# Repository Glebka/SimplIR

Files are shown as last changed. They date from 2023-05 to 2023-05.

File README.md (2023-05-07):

# SimplIR

The project of a joined IR Remote for controlling both Samsung LE26B450 TV and unknown TV Box that uses RC5 IR protocol.
SimplIR allows to switch TV On and Off, control volume and switch channels on TV Box.

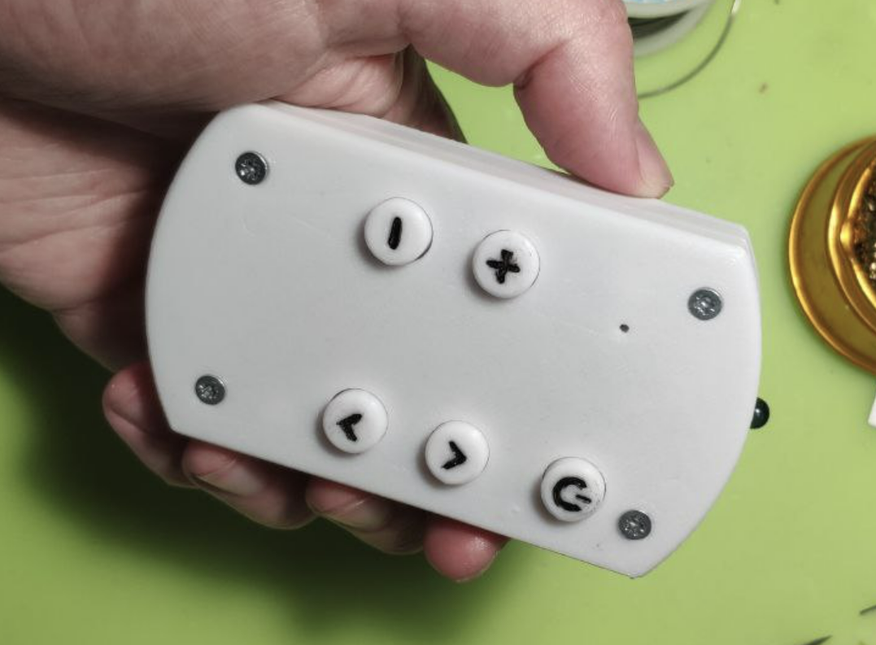
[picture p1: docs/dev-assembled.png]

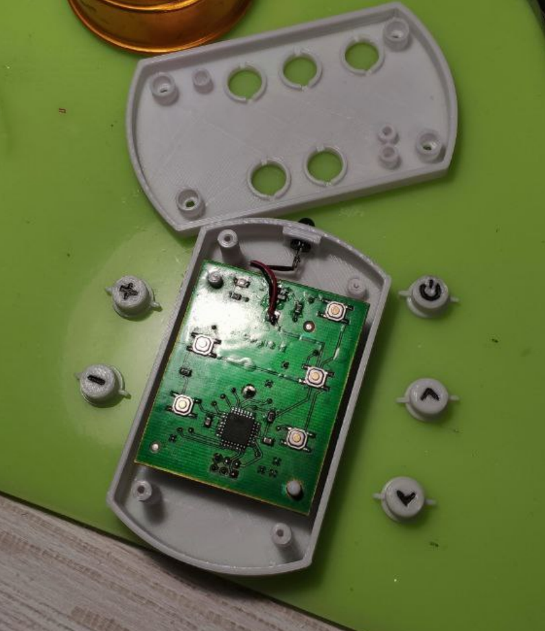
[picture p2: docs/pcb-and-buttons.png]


## Hardware and Software

* ATmega48PA MCU with Arduino based firmware
* 5 tactile buttons
* 1 5mm IR LED
* CR-2030 battery
* Firmware uses [Arduino-IRremote](https://github.com/Arduino-IRremote/Arduino-IRremote) for sending codes to the TV Set and TV Box
* Low power consumption - 0.1 uA, when in sleep mode (most of the time)

## TODO

* increase IR LED power, probably, add more LEDs in parallel
* add external crystal to guarantee precise timings
* deal with low recognition rate of ON/OFF signal for Samsung TV

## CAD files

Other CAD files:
cad/simplir-enclosure.FCStd

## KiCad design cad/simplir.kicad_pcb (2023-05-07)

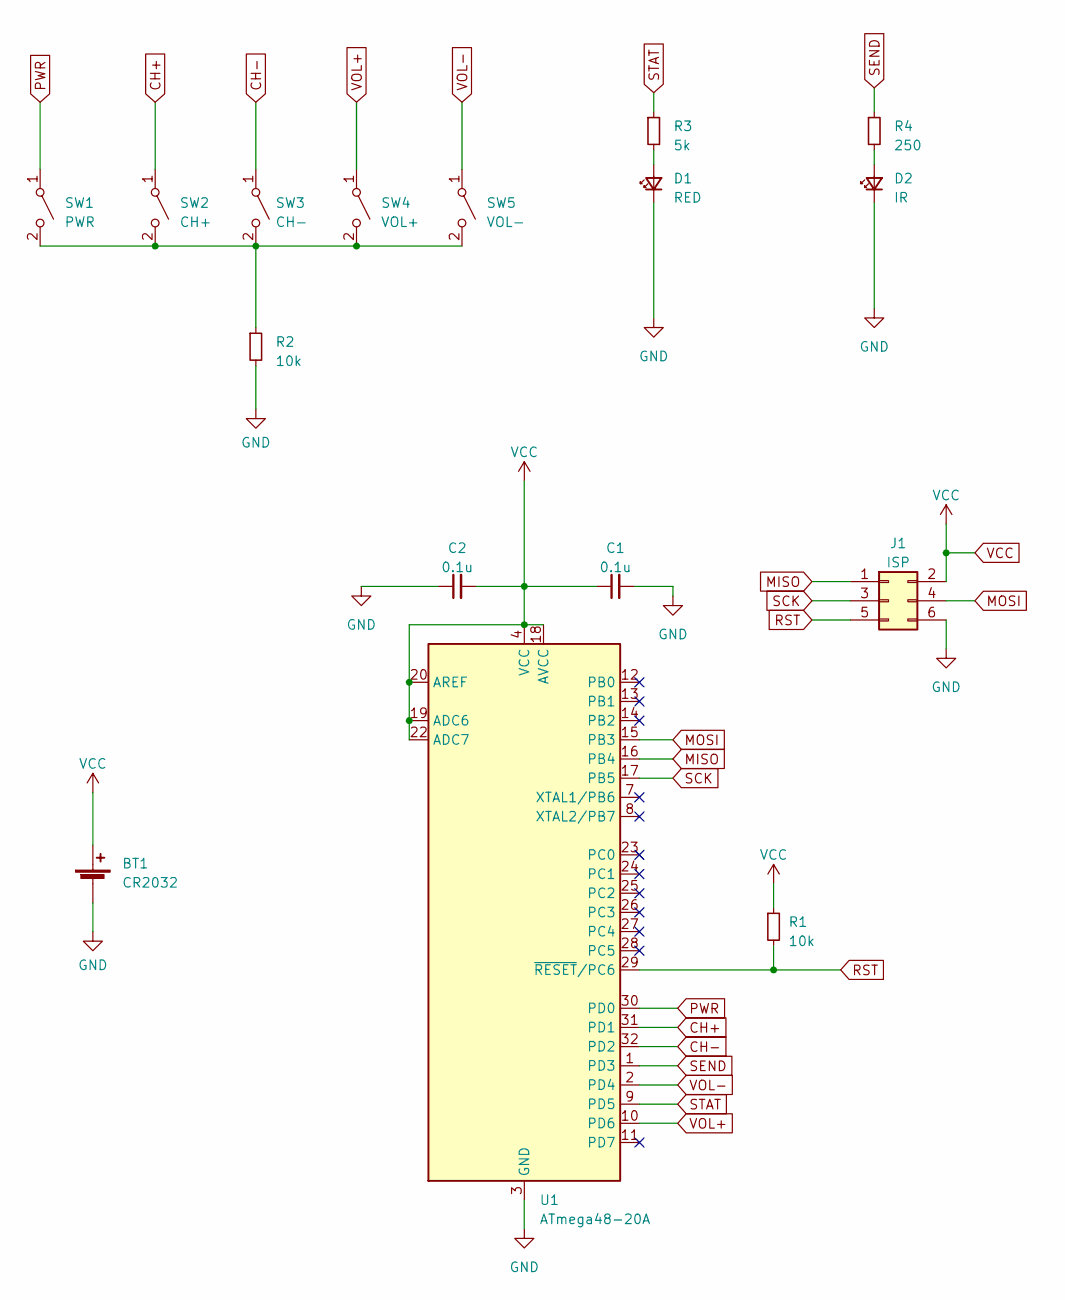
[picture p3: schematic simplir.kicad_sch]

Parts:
BT1: CR2032; BatteryHolder_Keystone_106_1x20mm
C1, C2: 0.1u; C_0805_2012Metric
D1: RED; LED_1206_3216Metric
D2: IR; LED_D5.0mm_IRGrey
J1: ISP; PinHeader_2x03_P2.54mm_Vertical
R1, R2: 10k; R_0805_2012Metric
R3: 5k; R_0805_2012Metric
R4: 250; R_0805_2012Metric
SW1: PWR; SW_SPST_TL3342
SW2: CH+; SW_SPST_TL3342
SW3: CH-; SW_SPST_TL3342
SW4: VOL+; SW_SPST_TL3342
SW5: VOL-; SW_SPST_TL3342
U1: ATmega48-20A; TQFP-32_7x7mm_P0.8mm

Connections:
CH+: SW2.1 (A), U1.31 (PD1)
CH-: SW3.1 (A), U1.32 (PD2)
GND: BT1.2 (-), C1.2, C2.1, D1.1 (K), D2.1 (K), J1.6, R2.2, U1.3 (GND), U1.5 (GND), U1.21 (GND)
MISO: J1.1, U1.16 (PB4)
MOSI: J1.4, U1.15 (PB3)
unnamed: D1.2 (A), R3.2
unnamed: D2.2 (A), R4.2
unnamed: R2.1, SW1.2 (B), SW2.2 (B), SW3.2 (B), SW4.2 (B), SW5.2 (B)
PWR: SW1.1 (A), U1.30 (PD0)
RST: J1.5, R1.2, U1.29 (~RESET/PC6)
SCK: J1.3, U1.17 (PB5)
SEND: R4.1, U1.1 (PD3)
STAT: R3.1, U1.9 (PD5)
VCC: BT1.1 (+), C1.1, C2.2, J1.2, R1.1, U1.4 (VCC), U1.6 (VCC), U1.18 (AVCC), U1.19 (ADC6), U1.20 (AREF), U1.22 (ADC7)
VOL+: SW4.1 (A), U1.10 (PD6)
VOL-: SW5.1 (A), U1.2 (PD4)

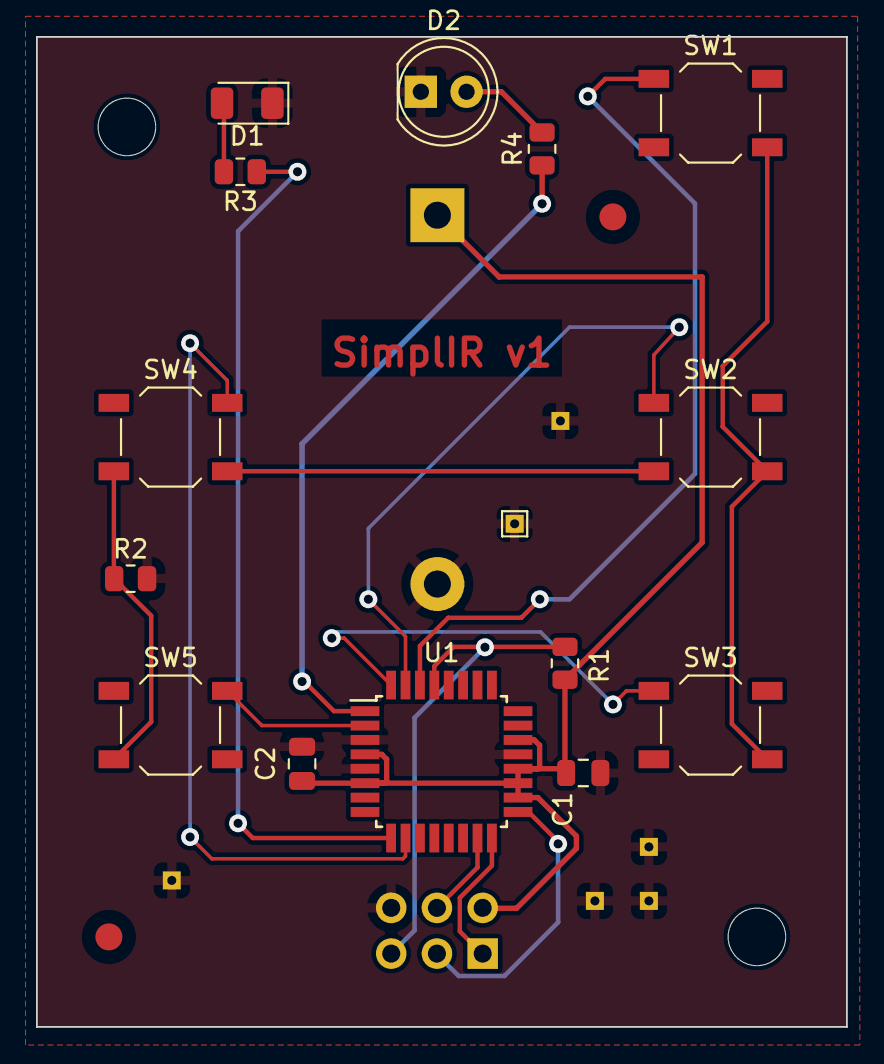
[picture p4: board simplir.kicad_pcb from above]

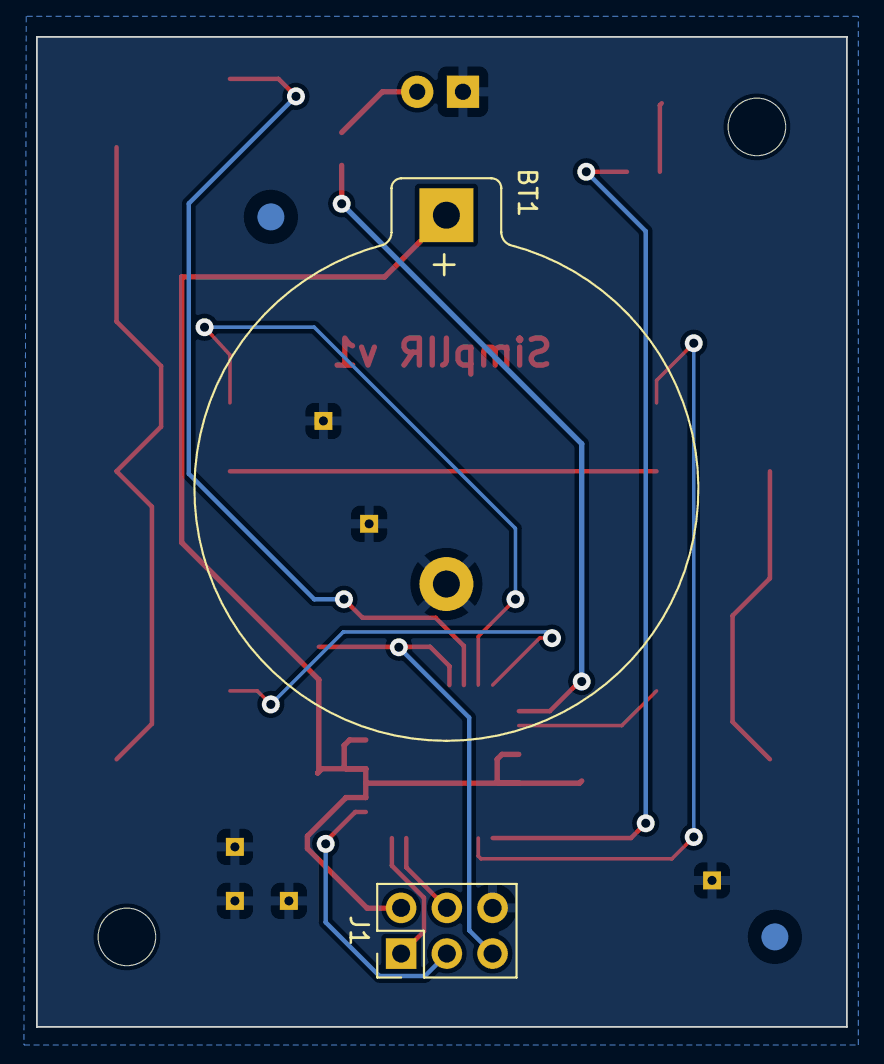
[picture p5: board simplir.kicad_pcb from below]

Board: 2 copper layers, 45.0 x 55.0 mm, 16 parts (2 on the bottom side), 16 nets.

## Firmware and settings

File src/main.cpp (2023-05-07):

#include <Arduino.h>
#define DISABLE_CODE_FOR_RECEIVER
#define SEND_PWM_BY_TIMER
#define IR_USE_AVR_TIMER2
#include <IRremote.hpp>
#include <TimerOne.h>
#include <avr/power.h>
#include <avr/sleep.h>

#define IR_LED_PIN (PD3)
#define LED_FEEDBACK_PIN (PD5)
#define TICK_INTERVAL (30000)
#define IDLE_TICKS_TIMEOUT (5)

/*
PWR   - PD0
CH+   - PD1
CH-   - PD2
VOL-  - PD4
VOL+  - PD6
*/

namespace Buttons
{
  enum
  {
    BTN_PWR,
    CH_PLUS,
    CH_MINUS,
    VOL_MINUS,
    VOL_PLUS,
    COUNT_
  };
}

typedef void (*SendFunc)(uint16_t, uint16_t);

struct ButtonHandler
{
  SendFunc send;
  uint16_t addr;
  uint16_t cmd;
};

void send_rc5(uint16_t addr, uint16_t cmd)
{
  IrSender.sendRC5((uint8_t)addr, (uint8_t)cmd, 0);
}

void send_samsung(uint16_t addr, uint16_t cmd)
{
  IrSender.sendSamsung(addr, cmd, 0);
}

volatile uint8_t button_pins[Buttons::COUNT_] = {PD0, PD1, PD2, PD4, PD6};
volatile uint8_t buttons_prev_state[Buttons::COUNT_] = {1, 1, 1, 1, 1};
volatile uint8_t buttons_state[Buttons::COUNT_] = {1, 1, 1, 1, 1};
volatile uint8_t tick = 0;
volatile uint8_t ticks_since_last_event = 0;
ButtonHandler button_handlers[Buttons::COUNT_] = {
    {send_samsung, 0x707, 0x2},
    {send_rc5, 0xE, 0x3C},
    {send_rc5, 0xE, 0x11},
    {send_rc5, 0xE, 0x13},
    {send_rc5, 0xE, 0x12},
};

void inc_tick()
{
  tick++;
  ticks_since_last_event++;
}

void setup()
{
  // disable ADC
  ADCSRA = 0;

  // turn off various modules
  power_all_disable();

  // but enable the necessary ones
  power_timer0_enable();
  power_timer1_enable();
  power_timer2_enable();

  // set input with pull-up for all ports
  DDRB = 0;
  DDRC = 0;
  DDRD = 0;
  PORTB = 255;
  PORTC = 255;
  PORTD = 255;

  // IR Led pin should be OUTPUT
  pinMode(IR_LED_PIN, OUTPUT);
  digitalWrite(IR_LED_PIN, LOW);

  // Feedback pin is OUTPUT as well
  pinMode(LED_FEEDBACK_PIN, OUTPUT);
  digitalWrite(LED_FEEDBACK_PIN, LOW);

  // enable interrupts for PD
  PCICR |= 0b00000100;

  // enable interrupts for D0, D1, D2, D4, D6
  PCMSK2 |= 0b01010111;

  IrSender.begin(true, LED_FEEDBACK_PIN);
  Timer1.initialize(TICK_INTERVAL);
  Timer1.attachInterrupt(inc_tick);
}

void power_down()
{
  set_sleep_mode(SLEEP_MODE_PWR_DOWN);
  cli();
  sleep_enable();
  sleep_bod_disable();
  sei();
  sleep_cpu();
}

void idle()
{
  set_sleep_mode(SLEEP_MODE_IDLE);
  cli();
  sleep_enable();
  sleep_bod_disable();
  sei();
  sleep_cpu();
}

void read_pins()
{
  for (uint8_t i = 0; i < Buttons::COUNT_; i++)
  {
    buttons_state[i] = digitalRead(button_pins[i]);
  }
}

void update_previous_state()
{
  for (uint8_t i = 0; i < Buttons::COUNT_; i++)
  {
    buttons_prev_state[i] = buttons_state[i];
  }
}

uint8_t get_released_button()
{
  for (uint8_t i = 0; i < Buttons::COUNT_; i++)
  {
    if (buttons_prev_state[i] == 0 && buttons_state[i] == 1)
    {
      return i;
    }
  }
  return Buttons::COUNT_;
}

void loop()
{
  if (tick)
  {
    cli();
    tick = 0;
    read_pins();
    uint8_t button_pressed = get_released_button();
    update_previous_state();
    digitalWrite(LED_FEEDBACK_PIN, LOW);
    if (button_pressed != Buttons::COUNT_)
    {
      sei();
      Timer1.stop();
      ButtonHandler *handler_ptr = &button_handlers[button_pressed];
      handler_ptr->send(handler_ptr->addr, handler_ptr->cmd);
      ticks_since_last_event = 0;
      digitalWrite(LED_FEEDBACK_PIN, HIGH);
      Timer1.start();
    }
    sei();
    if (ticks_since_last_event >= IDLE_TICKS_TIMEOUT)
    {
      power_down();
    }
  }
  idle();
}

EMPTY_INTERRUPT(PCINT2_vect);

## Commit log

2023-05-07 Fix Volume+ and Volume- buttons
    [main.cpp]
2023-05-07 Add CAD files and README
    [simplir-enclosure.FCStd, simplir.kicad_pcb, simplir.kicad_sch]
